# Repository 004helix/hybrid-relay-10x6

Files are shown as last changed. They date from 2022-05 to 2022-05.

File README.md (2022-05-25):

# 10-channel hybrid relay din-rail module

- 4 units width
- 12/24v dc input
- reverse polarity protection
- mechanical relay sockets - `Finder 93.11`
- reinforced insulation using `VOT8024AG` optocouplers
- snubberless triacs as SSR - `BTA12-800BW / BTA16-800BW`
- 250VAC/6A slim mechanical relays - `Finder 34.51 / TE V23092 / Hongfa HF41F`
- MCU - `ATmega164PA-MU / ATmega324PA-MU / ATmega644PA-MU`
- triac test button
- open-drain input

[BOM](BOM.md)

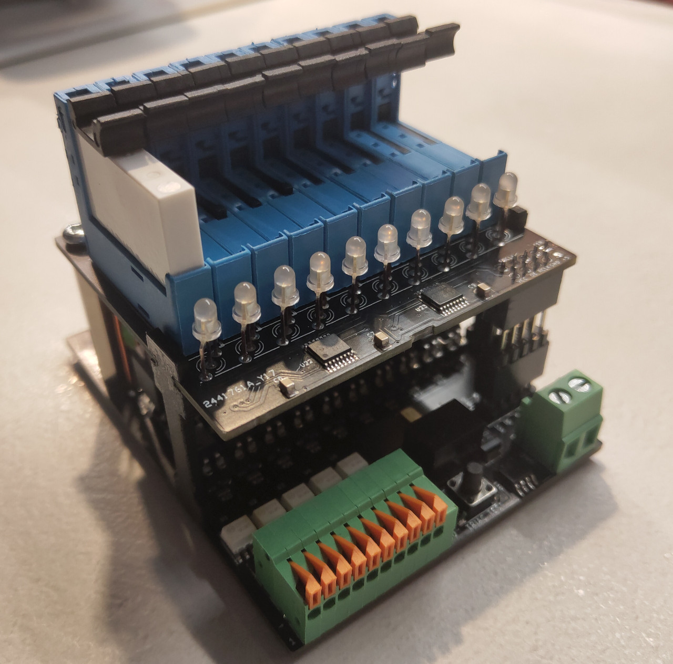
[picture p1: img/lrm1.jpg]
lrm1 Unboxed

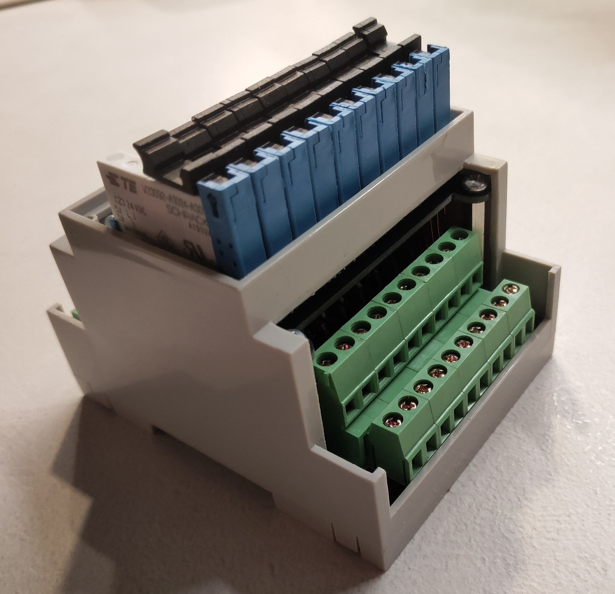
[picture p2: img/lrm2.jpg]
lrm2 Boxed

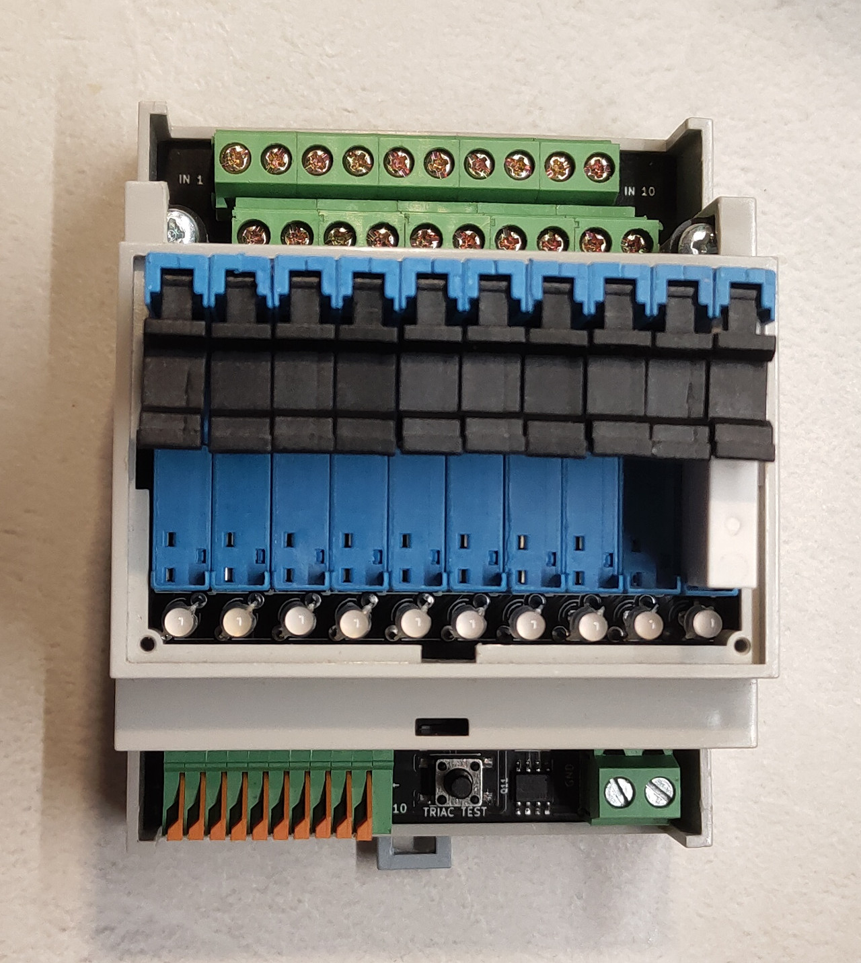
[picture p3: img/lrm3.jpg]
lrm3 Top


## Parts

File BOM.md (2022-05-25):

# BOM

| Ref Des | Qty | Manufacturer | Mfg Part # | Description / Value | Package |
| --- | --- | --- | --- | --- | --- |
| U1-U5 | 5 | onsemi | MOCD223M | Darlington Output Optocouplers | SOIC-8 |
| U6 | 1 | Mornsun / Recon / Aimtec | K7805-500R3 / R-78E5.0-0.5 / AMSR-7805-NZ | DC-DC converter | SIP-3 |
| U7 | 1 | Microchip Technology | ATmega164PA/324PA/644PA-MU | MCU | VQFN-44 |
| U8-U12,U14-U18 | 10  | Vishay Semiconductors | VOT8024AG | Opto-triac | DIP-4 |
| U13 | 1 | Texas Instruments | SN74LVC1G125DBVR | Single Bus Buffer Gate | SOT-23-5 |
| U19-U21 | 3 | Nexperia | 74HC595PW | 8-bit shift register | TSSOP-16 |
| U22-U23 | 2 | Texas Instruments | ULN2003APW | Darlington transistor array | TSSOP-16 |
| Y1 | 1 | any | Crystal 8.000Mhz | 8Mhz | SMD 5032 4Pin |
| SW1 | 1 | any | Push button | | SMD 6*6mm |
| C1-C2,C6-C9 | 7 | any | 100nF | Capacitor | 0805 |
| C3 | 1 | any | 15/22uF 35v | Tantalum Capacitor | SMD D |
| C4 | 1 | any | 15/22uF 10v | Tantalum Capacitor | SMD A |
| C5 | 1 | any | 10nF | Capacitor | 0805 |
| D1-D10 | 10  | any | 1N4148WS | Diode | SOD-323 |
| D11 | 1 | any | BZX84C10 | Zener diode 10V | SOT-23 |
| D12-D22 | 10  | G-NOR | GNL-3015UEUGW | Red/Green 3mm LED | THT |
| J1 | 1 | Degson / Phoenix Contact | DG141R-2.54-10P / 1789333 | | THT |
| J2 | 1 | any | Terminal block 5mm 2Pin | | THT |
| J3 | 5 | Degson / KLS Electronic  | DG500B-5.0-04P / KLS2-128IB-5.00-04P | | THT |
| J4,J7 | 20  | any | 35mm winding wire D0.8-1.0mm | | THT |
| J5 | 1 | any | 2.54mm 2x5 Pin Header | | THT |
| J6 | 1 | any | 2.54mm 2x5 Pin Socket | | THT |
| - | 1 | any | 2.54mm 2x5 Pin Socket Long Needle | | THT |
| K1-K10 | 10  | Finder | Finder 93.11 | Relay Socket | THT |
| - | 10  | Finder / Hongfa | 34.51.7 / HF41F | Relay 12/24v | THT |
| Q1-Q10 | 10  | STMicroelectronics | BTA12-800BWRG / BTA16-800BWRG | Snubberless triac | THT |
| Q11 | 1 | Infineon Technologies | IRF7241 | P-Channel MOSFET | SO-8 |
| R1-R10 | 10  | any | 24k | Resistor | 0603 |
| R11-R22,R76 | 13  | any | 10k | Resistor | 0603 |
| R23-R27,R40-R44 | 10  | any | 330 | Resistor | 0603 |
| R28,R65,R77 | 3 | any | 100k | Resistor | 0603 |
| R29 | 1 | any | 360 | Resistor | 0603 |
| R30,R32,R34,R36,R38,R45,R47,R49,R51,R53 | 10  | any | 390 | Resistor | 2512 |
| R31,R33,R35,R37,R39,R46,R48,R50,R52,R54 | 10  | any | 330 | Resistor | 2512 |
| R55-R64 | 10  | any | 3.3k | Resistor | 0603 |
| R66-R75 | 10  | any | 4.7k | Resistor | 0603 |
| - | 1 | Gainta | D4MG | Chassis | |

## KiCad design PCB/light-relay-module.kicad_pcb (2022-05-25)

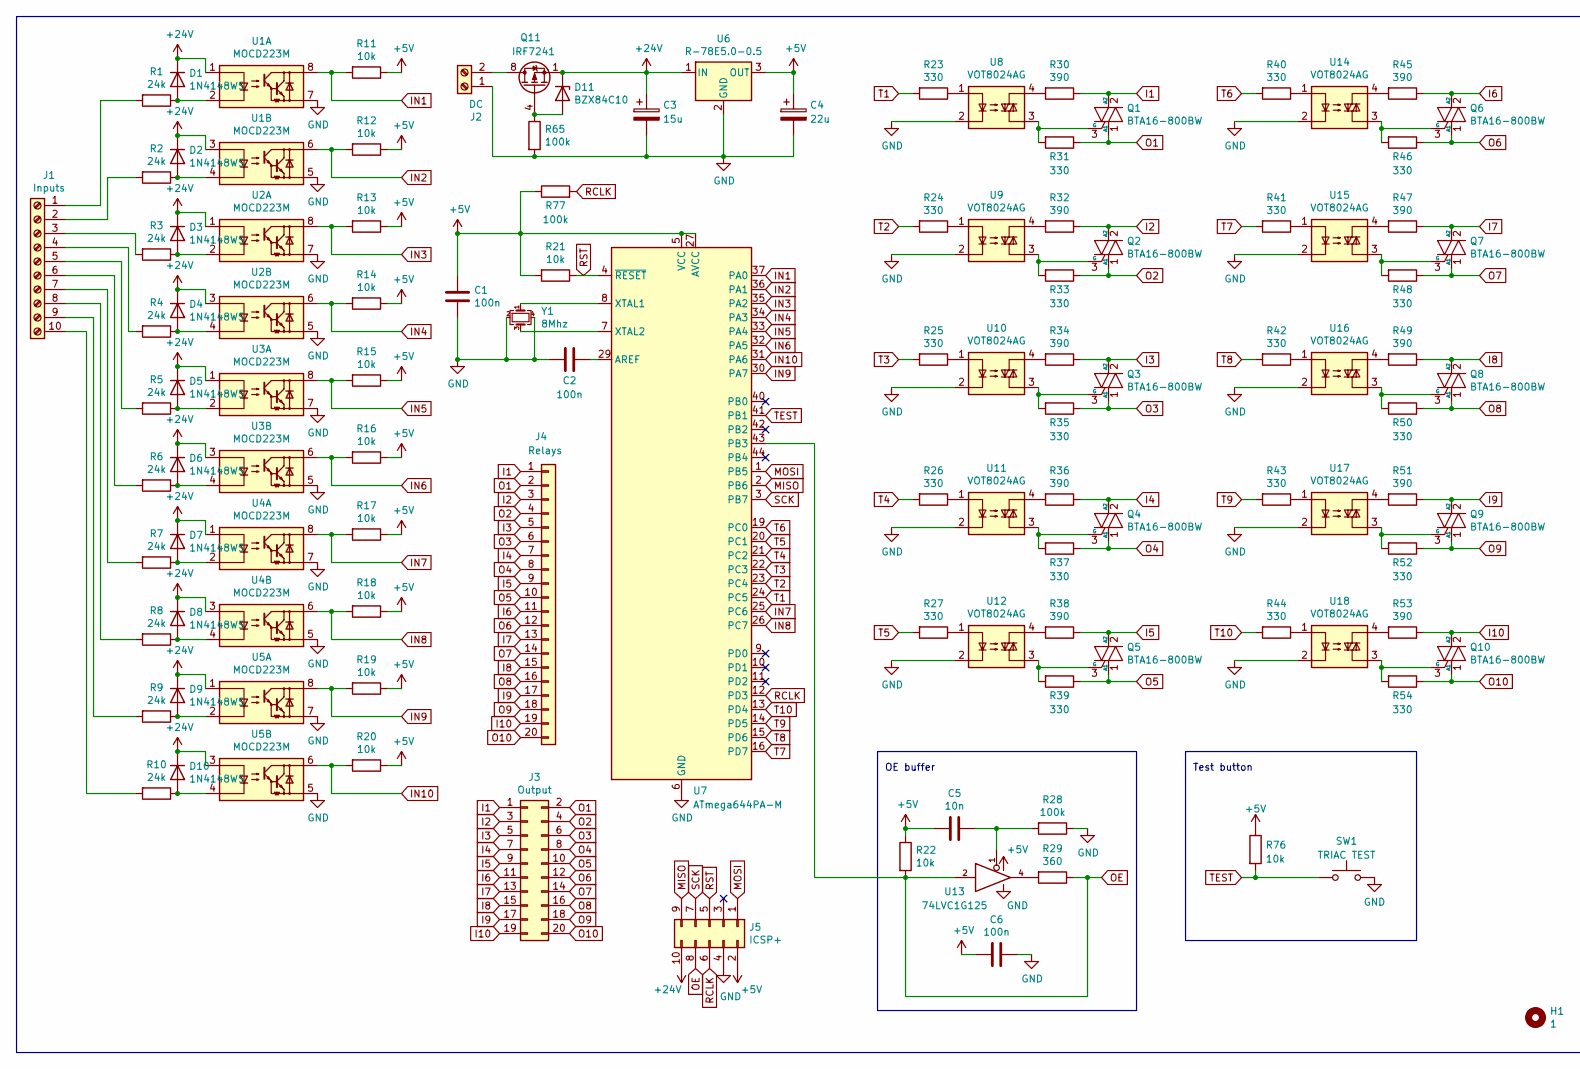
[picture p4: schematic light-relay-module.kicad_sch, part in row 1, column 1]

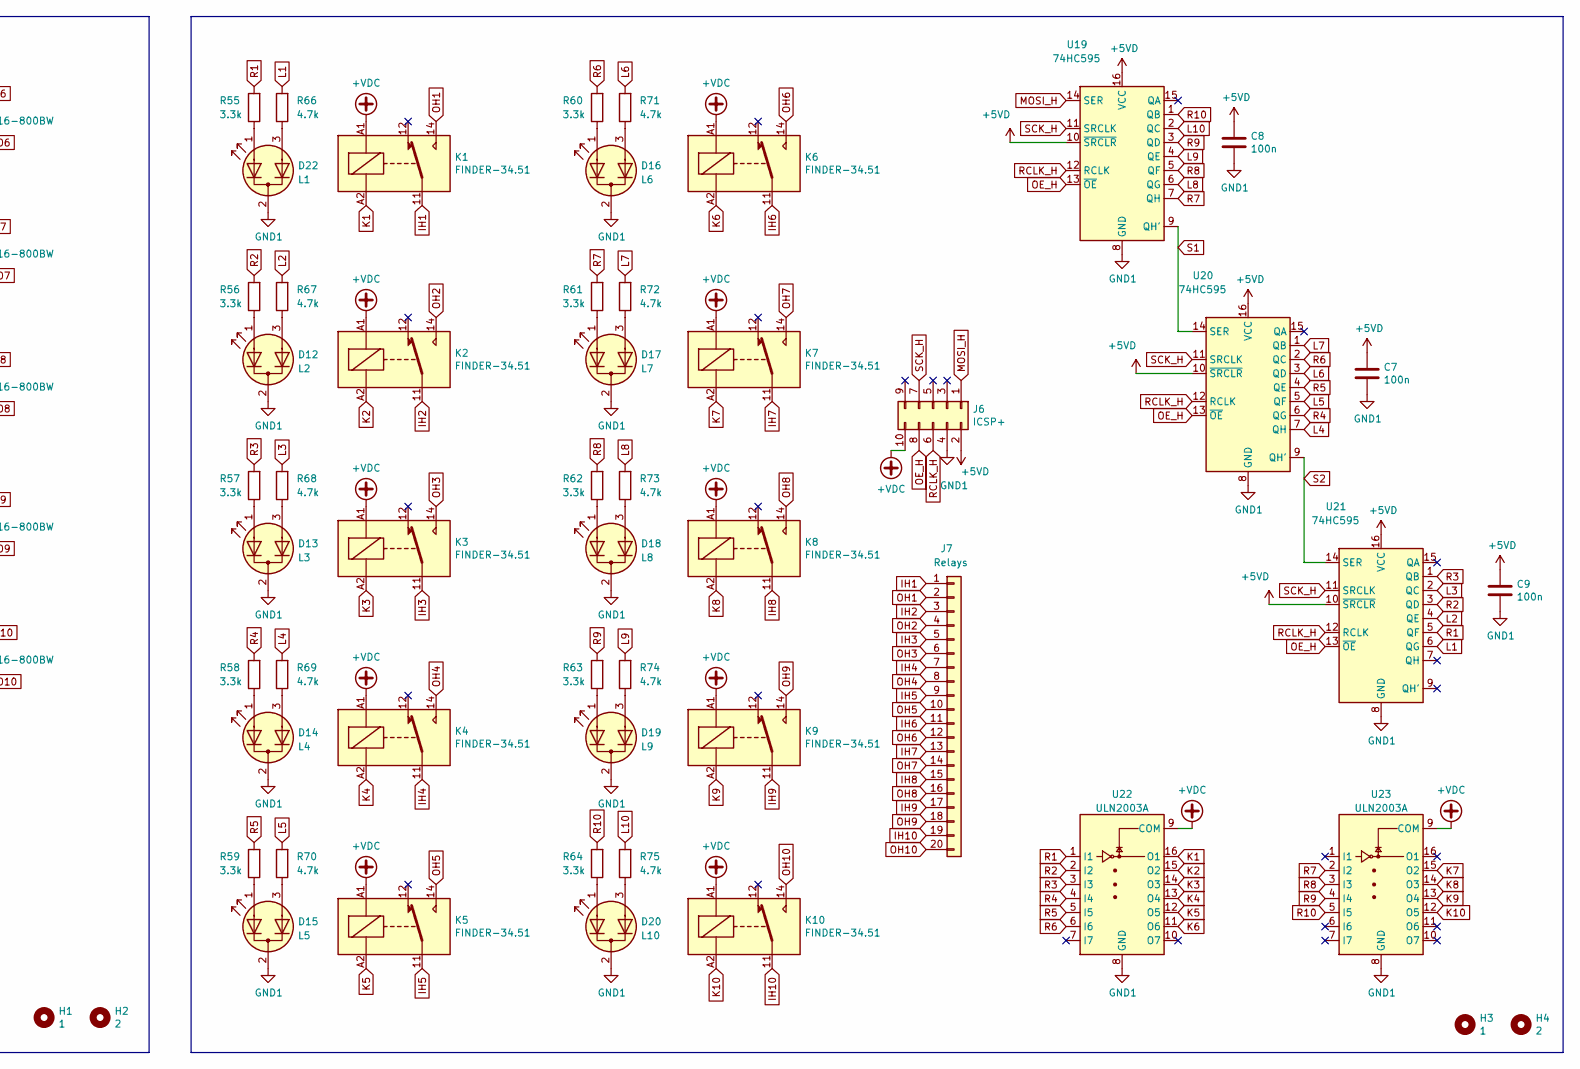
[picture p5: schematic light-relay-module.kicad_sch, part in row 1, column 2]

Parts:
C1, C2, C6, C7, C8, C9: 100n; C_0805_2012Metric
C3: 15u; CP_EIA-7343-40_Kemet-Y
C4: 22u; CP_EIA-3528-21_Kemet-B
C5: 10n; C_0805_2012Metric
D1, D2, D3, D4, D5, D6, D7, D8, D9, D10: 1N4148WS; D_SOD-323
D11: BZX84C10; D_SOT-23_ANK
D12: L2; LED_D3.0mm-3
D13: L3; LED_D3.0mm-3
D14: L4; LED_D3.0mm-3
D15: L5; LED_D3.0mm-3
D16: L6; LED_D3.0mm-3
D17: L7; LED_D3.0mm-3
D18: L8; LED_D3.0mm-3
D19: L9; LED_D3.0mm-3
D20: L10; LED_D3.0mm-3
D22: L1; LED_D3.0mm-3
H1, H3: 1; MountingHole_3.2mm_M3
H2, H4: 2; MountingHole_3.2mm_M3
J1: Inputs; DG141R-10P
J2: DC; TerminalBlock_Phoenix_MKDS-1,5-2_1x02_P5.00mm_Horizontal
J3: Output; DG500B-10P
J4, J7: Relays; Y20P
J5: ICSP+; PinHeader_2x05_P2.54mm_Vertical
J6: ICSP+; PinSocket_2x05_P2.54mm_Vertical
K1, K2, K3, K4, K5, K6, K7, K8, K9, K10: FINDER-34.51; Relay_SPDT_Finder_34.11
Q1, Q2, Q3, Q4, Q5, Q6, Q7, Q8, Q9, Q10: BTA16-800BW; TO-220-3_Vertical
Q11: IRF7241; SOIC-8_3.9x4.9mm_P1.27mm
R1, R2, R3, R4, R5, R6, R7, R8, R9, R10: 24k; R_0603_1608Metric
R11, R12, R13, R14, R15, R16, R17, R18, R19, R20, R21, R22, R76: 10k; R_0603_1608Metric
R23, R24, R25, R26, R27, R40, R41, R42, R43, R44: 330; R_0603_1608Metric
R28, R65, R77: 100k; R_0603_1608Metric
R29: 360; R_0603_1608Metric
R30, R32, R34, R36, R38, R45, R47, R49, R51, R53: 390; R_2512_6332Metric
R31, R33, R35, R37, R39, R46, R48, R50, R52, R54: 330; R_2512_6332Metric
R55, R56, R57, R58, R59, R60, R61, R62, R63, R64: 3.3k; R_0603_1608Metric
R66, R67, R68, R69, R70, R71, R72, R73, R74, R75: 4.7k; R_0603_1608Metric
SW1: TRIAC TEST; SW_Push_1P1T_NO_6x6mm_H9.5mm
U1, U2, U3, U4, U5: MOCD223M; SO-8_3.9x4.9mm_P1.27mm
U6: R-78E5.0-0.5; Converter_DCDC_RECOM_R-78E-0.5_THT
U7: ATmega644PA-M; QFN-44-1EP_7x7mm_P0.5mm_EP5.2x5.2mm
U8, U9, U10, U11, U12, U14, U15, U16, U17, U18: VOT8024AG; DIP-4_W7.62mm
U13: 74LVC1G125; SOT-23-5
U19, U20, U21: 74HC595; TSSOP-16_4.4x5mm_P0.65mm
U22, U23: ULN2003A; TSSOP-16_4.4x5mm_P0.65mm
Y1: 8Mhz; Crystal_SMD_5032-4Pin_5.0x3.2mm

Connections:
+5V: C1.1, C4.1, C5.2, C6.2, J5.2, R11.1, R12.1, R13.1, R14.1, R15.1, R16.1, R17.1, R18.1, R19.1, R20.1, R21.2, R22.1, R76.1, R77.1, U6.3 (OUT), U7.5 (VCC), U7.17 (VCC), U7.27 (AVCC), U7.38 (VCC), U13.5 (VCC)
+5VD: C7.1, C8.1, C9.1, J6.2, U19.10 (~SRCLR), U19.16 (VCC), U20.10 (~SRCLR), U20.16 (VCC), U21.10 (~SRCLR), U21.16 (VCC)
+24V: C3.1, D1.1 (K), D2.1 (K), D3.1 (K), D4.1 (K), D5.1 (K), D6.1 (K), D7.1 (K), D8.1 (K), D9.1 (K), D10.1 (K), D11.1 (K), J5.10, Q11.1 (S), Q11.2 (S), Q11.3 (S), U1.1, U1.3, U2.1, U2.3, U3.1, U3.3, U4.1, U4.3, U5.1, U5.3, U6.1 (IN)
+VDC: J6.10, K1.A1, K2.A1, K3.A1, K4.A1, K5.A1, K6.A1, K7.A1, K8.A1, K9.A1, K10.A1, U22.9 (COM), U23.9 (COM)
GND: C1.2, C2.2, C3.2, C4.2, C6.1, J2.1, J5.4, R28.1, R65.2, SW1.2, U1.5, U1.7, U2.5, U2.7, U3.5, U3.7, U4.5, U4.7, U5.5, U5.7, U6.2 (GND), U7.6 (GND), U7.18 (GND), U7.28 (GND), U7.39 (GND), U7.45 (GND), U8.2, U9.2, U10.2, U11.2, U12.2, U13.3 (GND), U14.2, U15.2, U16.2, U17.2, U18.2, Y1.2, Y1.4
GND1: C7.2, C8.2, C9.2, D12.2 (K), D13.2 (K), D14.2 (K), D15.2 (K), D16.2 (K), D17.2 (K), D18.2 (K), D19.2 (K), D20.2 (K), D22.2 (K), J6.4, U19.8 (GND), U20.8 (GND), U21.8 (GND), U22.8 (GND), U23.8 (GND)
I1: J3.1, J4.1, Q1.2 (A2), R30.1
I2: J3.3, J4.3, Q2.2 (A2), R32.1
I3: J3.5, J4.5, Q3.2 (A2), R34.1
I4: J3.7, J4.7, Q4.2 (A2), R36.1
I5: J3.9, J4.9, Q5.2 (A2), R38.1
I6: J3.11, J4.11, Q6.2 (A2), R45.1
I7: J3.13, J4.13, Q7.2 (A2), R47.1
I8: J3.15, J4.15, Q8.2 (A2), R49.1
I9: J3.17, J4.17, Q9.2 (A2), R51.1
I10: J3.19, J4.19, Q10.2 (A2), R53.1
IH1: J7.1, K1.11
IH2: J7.3, K2.11
IH3: J7.5, K3.11
IH4: J7.7, K4.11
IH5: J7.9, K5.11
IH6: J7.11, K6.11
IH7: J7.13, K7.11
IH8: J7.15, K8.11
IH9: J7.17, K9.11
IH10: J7.19, K10.11
IN1: R11.2, U1.8, U7.37 (PA0)
IN2: R12.2, U1.6, U7.36 (PA1)
IN3: R13.2, U2.8, U7.35 (PA2)
IN4: R14.2, U2.6, U7.34 (PA3)
IN5: R15.2, U3.8, U7.33 (PA4)
IN6: R16.2, U3.6, U7.32 (PA5)
IN7: R17.2, U4.8, U7.25 (PC6)
IN8: R18.2, U4.6, U7.26 (PC7)
IN9: R19.2, U5.8, U7.30 (PA7)
IN10: R20.2, U5.6, U7.31 (PA6)
K1: K1.A2, U22.16 (O1)
K2: K2.A2, U22.15 (O2)
K3: K3.A2, U22.14 (O3)
K4: K4.A2, U22.13 (O4)
K5: K5.A2, U22.12 (O5)
K6: K6.A2, U22.11 (O6)
K7: K7.A2, U23.15 (O2)
K8: K8.A2, U23.14 (O3)
K9: K9.A2, U23.13 (O4)
K10: K10.A2, U23.12 (O5)
L1: R66.2, U21.6 (QG)
L2: R67.2, U21.4 (QE)
L3: R68.2, U21.2 (QC)
L4: R69.2, U20.7 (QH)
L5: R70.2, U20.5 (QF)
L6: R71.2, U20.3 (QD)
L7: R72.2, U20.1 (QB)
L8: R73.2, U19.6 (QG)
L9: R74.2, U19.4 (QE)
L10: R75.2, U19.2 (QC)
MISO: J5.9, U7.2 (PB6)
MOSI: J5.1, U7.1 (PB5)
MOSI_H: J6.1, U19.14 (SER)
unnamed: C2.1, U7.29 (AREF)
unnamed: C5.1, R28.2, U13.1
unnamed: D1.2 (A), R1.1, U1.2
unnamed: D2.2 (A), R2.1, U1.4
unnamed: D3.2 (A), R3.1, U2.2
unnamed: D4.2 (A), R4.1, U2.4
unnamed: D5.2 (A), R5.1, U3.2
unnamed: D6.2 (A), R6.1, U3.4
unnamed: D7.2 (A), R7.1, U4.2
unnamed: D8.2 (A), R8.1, U4.4
unnamed: D9.2 (A), R9.1, U5.2
unnamed: D10.2 (A), R10.1, U5.4
unnamed: D11.2 (A), Q11.4 (G), R65.1
unnamed: D12.1 (A1), R56.1
unnamed: D12.3 (A2), R67.1
unnamed: D13.1 (A1), R57.1
unnamed: D13.3 (A2), R68.1
unnamed: D14.1 (A1), R58.1
unnamed: D14.3 (A2), R69.1
unnamed: D15.1 (A1), R59.1
unnamed: D15.3 (A2), R70.1
unnamed: D16.1 (A1), R60.1
unnamed: D16.3 (A2), R71.1
unnamed: D17.1 (A1), R61.1
unnamed: D17.3 (A2), R72.1
unnamed: D18.1 (A1), R62.1
unnamed: D18.3 (A2), R73.1
unnamed: D19.1 (A1), R63.1
unnamed: D19.3 (A2), R74.1
unnamed: D20.1 (A1), R64.1
unnamed: D20.3 (A2), R75.1
unnamed: D22.1 (A1), R55.1
unnamed: D22.3 (A2), R66.1
unnamed: J1.1, R1.2
unnamed: J1.2, R2.2
unnamed: J1.3, R3.2
unnamed: J1.4, R4.2
unnamed: J1.5, R5.2
unnamed: J1.6, R6.2
unnamed: J1.7, R7.2
unnamed: J1.8, R8.2
unnamed: J1.9, R9.2
unnamed: J1.10, R10.2
unnamed: J2.2, Q11.5 (D), Q11.6 (D), Q11.7 (D), Q11.8 (D)
unnamed: Q1.3 (G), R31.2, U8.3
unnamed: Q2.3 (G), R33.2, U9.3
unnamed: Q3.3 (G), R35.2, U10.3
unnamed: Q4.3 (G), R37.2, U11.3
unnamed: Q5.3 (G), R39.2, U12.3
unnamed: Q6.3 (G), R46.2, U14.3
unnamed: Q7.3 (G), R48.2, U15.3
unnamed: Q8.3 (G), R50.2, U16.3
unnamed: Q9.3 (G), R52.2, U17.3
unnamed: Q10.3 (G), R54.2, U18.3
unnamed: R23.1, U8.1
unnamed: R24.1, U9.1
unnamed: R25.1, U10.1
unnamed: R26.1, U11.1
unnamed: R27.1, U12.1
unnamed: R29.2, U13.4
unnamed: R30.2, U8.4
unnamed: R32.2, U9.4
unnamed: R34.2, U10.4
unnamed: R36.2, U11.4
unnamed: R38.2, U12.4
unnamed: R40.1, U14.1
unnamed: R41.1, U15.1
unnamed: R42.1, U16.1
unnamed: R43.1, U17.1
unnamed: R44.1, U18.1
unnamed: R45.2, U14.4
unnamed: R47.2, U15.4
unnamed: R49.2, U16.4
unnamed: R51.2, U17.4
unnamed: R53.2, U18.4
unnamed: U7.7 (XTAL2), Y1.3
unnamed: U7.8 (XTAL1), Y1.1
O1: J3.2, J4.2, Q1.1 (A1), R31.1
O2: J3.4, J4.4, Q2.1 (A1), R33.1
O3: J3.6, J4.6, Q3.1 (A1), R35.1
O4: J3.8, J4.8, Q4.1 (A1), R37.1
O5: J3.10, J4.10, Q5.1 (A1), R39.1
O6: J3.12, J4.12, Q6.1 (A1), R46.1
O7: J3.14, J4.14, Q7.1 (A1), R48.1
O8: J3.16, J4.16, Q8.1 (A1), R50.1
O9: J3.18, J4.18, Q9.1 (A1), R52.1
O10: J3.20, J4.20, Q10.1 (A1), R54.1
OE: J5.8, R22.2, R29.1, U7.43 (PB3), U13.2
OE_H: J6.8, U19.13 (~OE), U20.13 (~OE), U21.13 (~OE)
OH1: J7.2, K1.14
OH2: J7.4, K2.14
OH3: J7.6, K3.14
OH4: J7.8, K4.14
OH5: J7.10, K5.14
OH6: J7.12, K6.14
OH7: J7.14, K7.14
OH8: J7.16, K8.14
OH9: J7.18, K9.14
OH10: J7.20, K10.14
R1: R55.2, U21.5 (QF), U22.1 (I1)
R2: R56.2, U21.3 (QD), U22.2 (I2)
R3: R57.2, U21.1 (QB), U22.3 (I3)
R4: R58.2, U20.6 (QG), U22.4 (I4)
R5: R59.2, U20.4 (QE), U22.5 (I5)
R6: R60.2, U20.2 (QC), U22.6 (I6)
R7: R61.2, U19.7 (QH), U23.2 (I2)
R8: R62.2, U19.5 (QF), U23.3 (I3)
R9: R63.2, U19.3 (QD), U23.4 (I4)
R10: R64.2, U19.1 (QB), U23.5 (I5)
RCLK: J5.6, R77.2, U7.12 (PD3)
RCLK_H: J6.6, U19.12 (RCLK), U20.12 (RCLK), U21.12 (RCLK)
RST: J5.5, R21.1, U7.4 (~RESET)
S1: U19.9 (QH'), U20.14 (SER)
S2: U20.9 (QH'), U21.14 (SER)
SCK: J5.7, U7.3 (PB7)
SCK_H: J6.7, U19.11 (SRCLK), U20.11 (SRCLK), U21.11 (SRCLK)
T1: R23.2, U7.24 (PC5)
T2: R24.2, U7.23 (PC4)
T3: R25.2, U7.22 (PC3)
T4: R26.2, U7.21 (PC2)
T5: R27.2, U7.20 (PC1)
T6: R40.2, U7.19 (PC0)
T7: R41.2, U7.16 (PD7)
T8: R42.2, U7.15 (PD6)
T9: R43.2, U7.14 (PD5)
T10: R44.2, U7.13 (PD4)
TEST: R76.2, SW1.1, U7.41 (PB1)

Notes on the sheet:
OE buffer
Test button

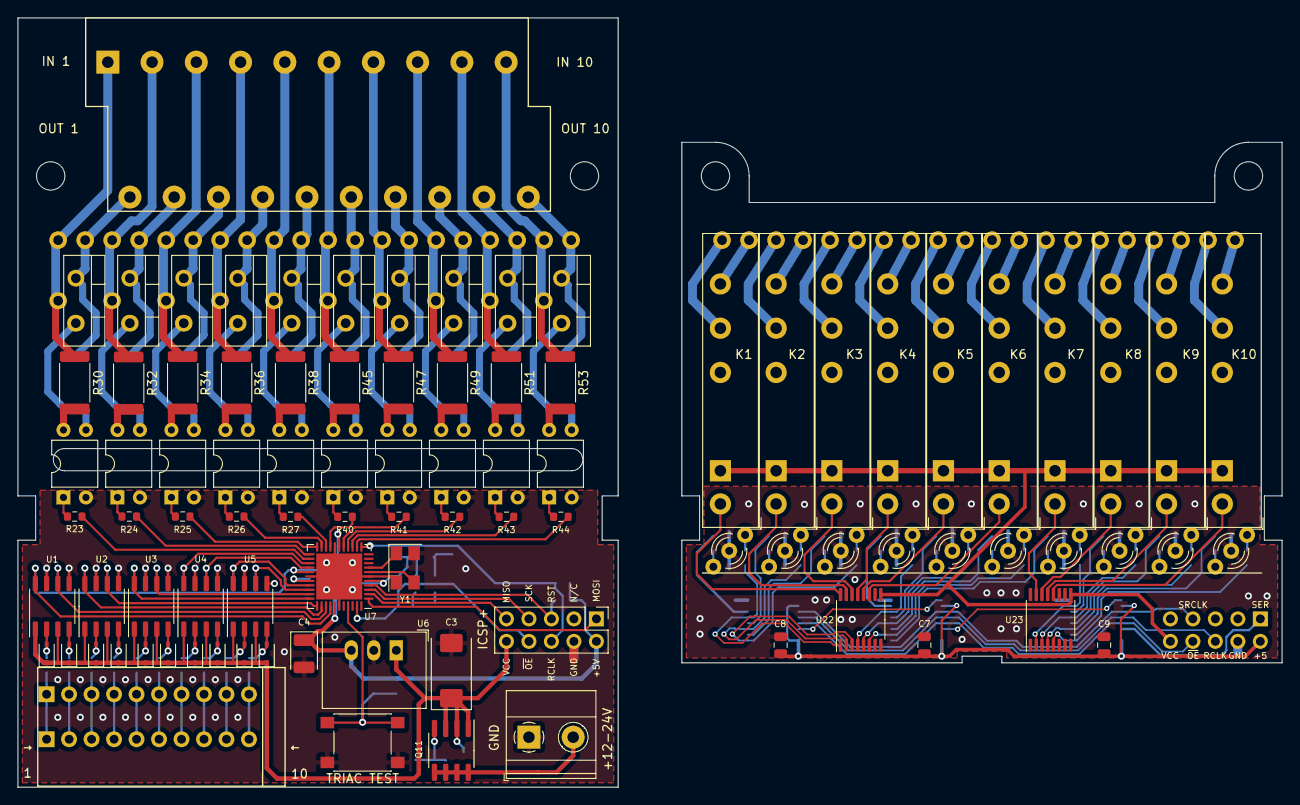
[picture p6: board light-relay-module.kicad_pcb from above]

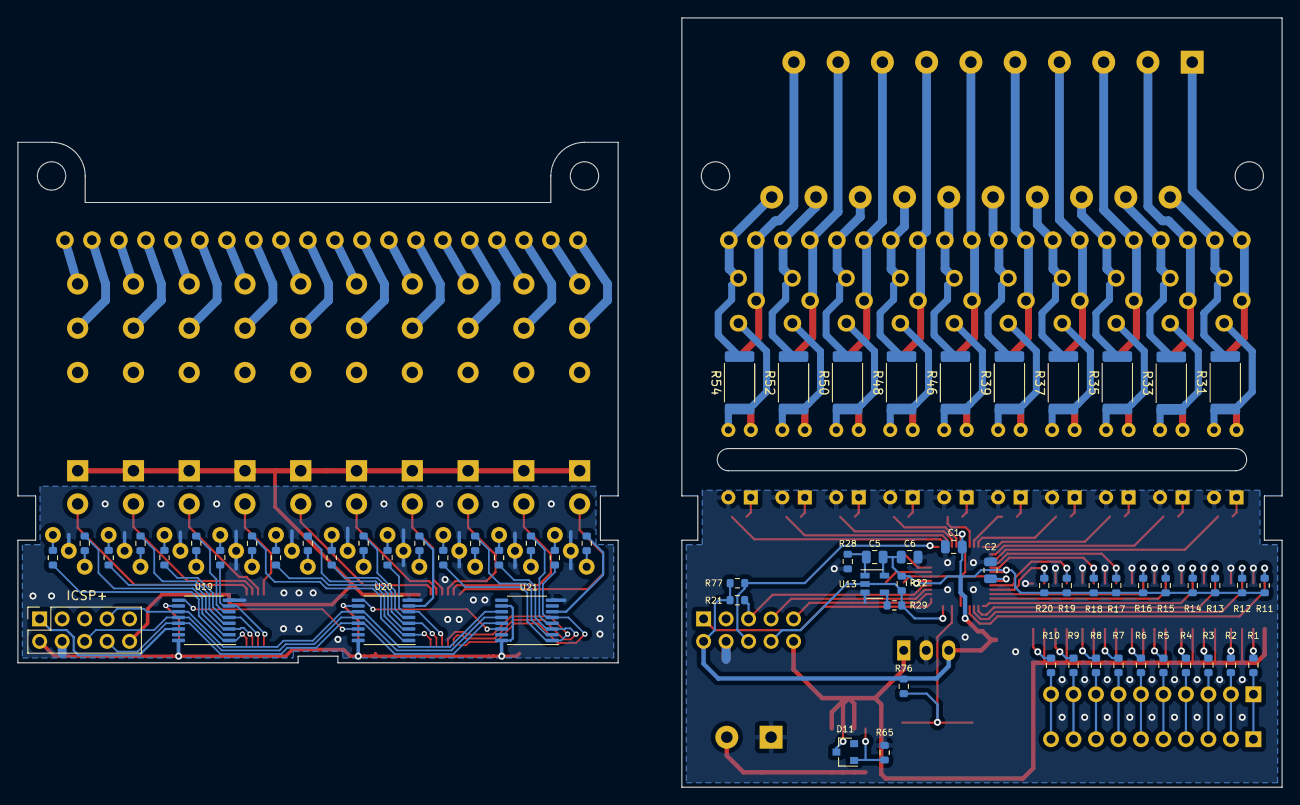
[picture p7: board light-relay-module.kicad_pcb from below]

Board: 2 copper layers, 142.8 x 86.9 mm, 164 parts (67 on the bottom side), 186 nets.

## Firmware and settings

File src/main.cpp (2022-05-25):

/*
 * This file is released under the GPL.
 */

#include <avr/wdt.h>
#include <avr/sleep.h>
#include <Arduino.h>
#include <SPI.h>

#define KHZ 1000UL
#define MHZ 1000000ULL

// shift register array and button pins
#define RCLK        PIN_PD3
#define OE          PIN_PB3
#define SER_IN      PIN_SPI_MOSI  // PB5
#define SRCK        PIN_SPI_SCK   // PB7
#define TRIAC_TEST  PIN_PB1

// spi settings
SPISettings ss(4*MHZ, MSBFIRST, SPI_MODE0);

// shift registers: U19, U20, U21
uint8_t regs[3] = {0, 0, 0};
#define U19 0
#define U20 1
#define U21 2

// triacs (pins) and triac leds (shift registers)
uint8_t triac[10] = {
    PIN_PC5, PIN_PC4, PIN_PC3, PIN_PC2, PIN_PC1,
    PIN_PC0, PIN_PD7, PIN_PD6, PIN_PD5, PIN_PD4
};
struct {
    uint8_t uc;
    uint8_t mask;
} tled[10] = {
    {U21, _BV(6)}, {U21, _BV(4)}, {U21, _BV(2)}, {U20, _BV(7)}, {U20, _BV(5)},
    {U20, _BV(3)}, {U20, _BV(1)}, {U19, _BV(6)}, {U19, _BV(4)}, {U19, _BV(2)}
};
#define triac_on(n)   do { digitalWrite(triac[n], HIGH); regs[tled[n].uc] |= tled[n].mask; } while (0)
#define triac_off(n)  do { digitalWrite(triac[n], LOW); regs[tled[n].uc] &= ~tled[n].mask; } while (0)

// relays (shift registers)
struct {
    uint8_t uc;
    uint8_t mask;
} relay[10] = {
    {U21, _BV(5)}, {U21, _BV(3)}, {U21, _BV(1)}, {U20, _BV(6)}, {U20, _BV(4)},
    {U20, _BV(2)}, {U19, _BV(7)}, {U19, _BV(5)}, {U19, _BV(3)}, {U19, _BV(1)}
};
#define relay_on(n)   do { regs[relay[n].uc] |= relay[n].mask; } while (0)
#define relay_off(n)  do { regs[relay[n].uc] &= ~relay[n].mask; } while (0)

// delays
#define DEBOUNCE_DELAY  10   // delay from last pin change interrupt
#define TRIAC_DELAY     40   // triac on time before relay switch on
#define RELAY_DELAY     100  // relay set time + triac release delay

// channel states
enum {
    CH_OFF = 0,       // triac off, relay off
    CH_OFF2ON_1,      // triac on,  relay off
    CH_OFF2ON_2,      // triac on,  relay on
    CH_ON,            // triac off, relay on
    CH_ON_TEST        // triac on,  relay off
} st[10];             // channels current state
bool ch[10];          // channels target state
unsigned long ms[10]; // channels timers
uint8_t duty = 0;     // sleep cpu disallowed if duty > 0

// pin change interrupts / debounce
volatile bool pcintrA = false;
volatile bool pcintrB = false;
volatile bool pcintrC = false;
unsigned long debounceA_start;
unsigned long debounceB_start;
unsigned long debounceC_start;
bool debounceA = false;
bool debounceB = false;
bool debounceC = false;
bool triac_test;


// PCINT0-PCINT7
ISR(PCINT0_vect)
{
    pcintrA = true;
}


// PCINT8-PCINT15
ISR(PCINT1_vect)
{
    pcintrB = true;
}


// PCINT16-PCINT23
ISR(PCINT2_vect)
{
    pcintrC = true;
}


bool input_get(uint8_t n)
{
    if (n < 6)
        return !(PINA & _BV(n));
    if (n < 8)
        return !(PINC & _BV(n));
    if (n < 10)
        return !(PINA & _BV(15 - n));

    return false;
}


void shift_out(void)
{
    SPI.beginTransaction(ss);
    digitalWrite(RCLK, LOW);
    SPI.transfer(regs[U21]);
    SPI.transfer(regs[U20]);
    SPI.transfer(regs[U19]);
    digitalWrite(RCLK, HIGH);
    SPI.endTransaction();
}


void setup()
{
    uint8_t i;

    // disable ADC
    ADCSRA = 0;

    // enable watchdog
    wdt_reset();
    wdt_enable(WDTO_1S);

    // set sleep mode
    set_sleep_mode(SLEEP_MODE_PWR_DOWN);

    // 500ms delay on boot
    for (i = 0; i < 10; i++) {
        delay(50);
        wdt_reset();
    }

    cli();
    // disable PA0-PA7 pull-ups
    PORTA = 0;
    // PA0-PA7 inputs
    DDRA = 0;
    // disable PB0-PB3,PB5-PB7 pull-ups, PB4 (SS) to low
    PORTB = 0;
    // PB4 (SS) output
    DDRB = (1 << DDB4);
    // disable PC6-PC7 pull-ups, PC0-PC5 to low
    PORTC = 0;
    // PC0-PC5 outputs
    DDRC = (1 << DDC5) | (1 << DDC4) | (1 << DDC3) | (1 << DDC2) | (1 << DDC1) | (1 << DDC0);
    // disable PD0-PD2 pull-ups, PD3 (RCLK) to high, PD4-PD7 to low
    PORTD = (1 << PD3);
    // PD3-PD7 outputs
    DDRD = (1 << DDD7) | (1 << DDD6) | (1 << DDD5) | (1 << DDD4) | (1 << DDD3);
    // PCINT0-PCINT7
    PCMSK0 = (1 << PCINT7) | (1 << PCINT6) | (1 << PCINT5) | (1 << PCINT4) | (1 << PCINT3) | (1 << PCINT2) | (1 << PCINT1) | (1 << PCINT0);
    // PCINT9
    PCMSK1 = (1 << PCINT9);
    // PCINT22-PCINT23
    PCMSK2 = (1 << PCINT23) | (1 << PCINT22);
    // enable ports A, B and C pin change interrupts
    PCICR = (1 << PCIE2) | (1 << PCIE1) | (1 << PCIE0);
    // enable interrupts
    sei();

    // setup SPI
    SPI.begin();

    // init channel states
    for (i = 0; i < 10; i++) {
        ch[i] = false;
        st[i] = CH_OFF;
    }

    // triac test button
    triac_test = (digitalRead(TRIAC_TEST) == LOW);

    if (digitalRead(OE) == LOW) {
        // soft reset (WD?)
        // enable output
        pinMode(OE, OUTPUT);

        for (i = 0; i < 10; i++) {
            if (input_get(i)) {
                ch[i] = true;
                if (triac_test) {
                    st[i] = CH_ON_TEST;
                    triac_on(i);
                } else {
                    st[i] = CH_ON;
                    relay_on(i);
                }
            }
        }

        shift_out();
    } else {
        // cold start
        unsigned long now = millis();

        for (i = 0; i < 10; i++) {
            if (input_get(i)) {
                ch[i] = true;
                st[i] = CH_OFF2ON_1;
                ms[i] = now;
                triac_on(i);
                duty++;
            }
        }

        shift_out();

        // enable output
        pinMode(OE, OUTPUT);
    }
}


void loop()
{
    bool shift_update = false;
    unsigned long now;
    uint8_t i;

    // one of inputs on port A was changed
    if (pcintrA) {
        if (!debounceA) {
            debounceA = true;
            duty++;
        }
        debounceA_start = millis();
        pcintrA = false;
    }

    // one of inputs on port B was changed
    if (pcintrB) {
        if (!debounceB) {
            debounceB = true;
            duty++;
        }
        debounceB_start = millis();
        pcintrB = false;
    }

    // one of inputs on port C was changed
    if (pcintrC) {
        if (!debounceC) {
            debounceC = true;
            duty++;
        }
        debounceC_start = millis();
        pcintrC = false;
    }

    // sleep cpu
    cli();
    if (duty == 0) {
        //SPI.end();
        //pinMode(PIN_SPI_MISO, OUTPUT);
        //digitalWrite(PIN_SPI_MISO, HIGH);
        wdt_disable();
        sleep_enable();
        sei();
        sleep_cpu();
        sleep_disable();
        wdt_enable(WDTO_1S);
        //digitalWrite(PIN_SPI_MISO, LOW);
        //pinMode(PIN_SPI_MISO, INPUT);
        //SPI.begin();
    }
    sei();

    now = millis();

    // debounce port A delay
    if (debounceA && (now - debounceA_start) > DEBOUNCE_DELAY) {
        // update channels
        uint8_t i, pina = PINA;

        for (i = 0; i < 6; i++)
            ch[i] = !(pina & _BV(i));

        ch[8] = !(pina & _BV(7));
        ch[9] = !(pina & _BV(6));

        debounceA = false;
        duty--;
    }

    // debounce port B delay
    if (debounceB && (now - debounceB_start) > DEBOUNCE_DELAY) {
        // update triac test
        triac_test = (digitalRead(TRIAC_TEST) == LOW);
        debounceB = false;
        duty--;
    }

    // debounce port C delay
    if (debounceC && (now - debounceC_start) > DEBOUNCE_DELAY) {
        // update channels
        uint8_t pinc = PINC;
        ch[6] = !(pinc & _BV(6));
        ch[7] = !(pinc & _BV(7));
        debounceC = false;
        duty--;
    }

    // process channels
    for (i = 0; i < 10; i++) {
        if (ch[i]) {
            // channel should be enabled
            switch (st[i]) {
                // (OFF)---(TRIAC ON)---(RELAY ON)---(TRIAC OFF)---(ON)
                //      ^^^
                case CH_OFF:
                    shift_update = true;
                    st[i] = CH_OFF2ON_1;
                    ms[i] = now;
                    triac_on(i);
                    duty++;
                    break;
                // (OFF)---(TRIAC ON)---(RELAY ON)---(TRIAC OFF)---(ON)
                //                    \----------------------------(TEST)
                //                   ^^^
                case CH_OFF2ON_1:
                    if ((now - ms[i]) >= TRIAC_DELAY) {
                        if (triac_test) {
                            st[i] = CH_ON_TEST;
                            duty--;
                        } else {
                            shift_update = true;
                            st[i] = CH_OFF2ON_2;
                            ms[i] = now;
                            relay_on(i);
                        }
                    }
                    break;
                // (OFF)---(TRIAC ON)---(RELAY ON)---(TRIAC OFF)---(ON)
                //                                 \-(RELAY OFF)---(TEST)
                //                                ^^^
                case CH_OFF2ON_2:
                    if (triac_test) {
                        shift_update = true;
                        st[i] = CH_ON_TEST;
                        relay_off(i);
                        duty--;
                    } else
                    if ((now - ms[i]) >= RELAY_DELAY) {
                        shift_update = true;
                        st[i] = CH_ON;
                        triac_off(i);
                        duty--;
                    }
                    break;
                // triac test button push
                //
                case CH_ON:
                    if (triac_test) {
                        shift_update = true;
                        st[i] = CH_ON_TEST;
                        relay_off(i);
                        triac_on(i);
                    }
                    break;
                // triac test button release
                //
                case CH_ON_TEST:
                    if (!triac_test) {
                        st[i] = CH_OFF2ON_1;
                        ms[i] = now;
                        duty++;
                    }
                    break;
            }
        } else {
            // channel should be disabled
            switch (st[i]) {
                // channel already switched off
                //
                case CH_OFF:
                    break;
                // switch off triac and relay
                //
                case CH_OFF2ON_1:
                case CH_OFF2ON_2:
                    duty--;
                case CH_ON:
                case CH_ON_TEST:
                    shift_update = true;
                    st[i] = CH_OFF;
                    triac_off(i);
                    relay_off(i);
                    break;
            }
        }
    }

    if (shift_update)
        shift_out();

    wdt_reset();
}

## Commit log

2022-05-25 fix CH_OFF2ON_2 if test button pressed
    [main.cpp]
2022-05-25 Add BOM, rename optocouplers
    [light-relay-module.kicad_pcb, light-relay-module.kicad_sch]
